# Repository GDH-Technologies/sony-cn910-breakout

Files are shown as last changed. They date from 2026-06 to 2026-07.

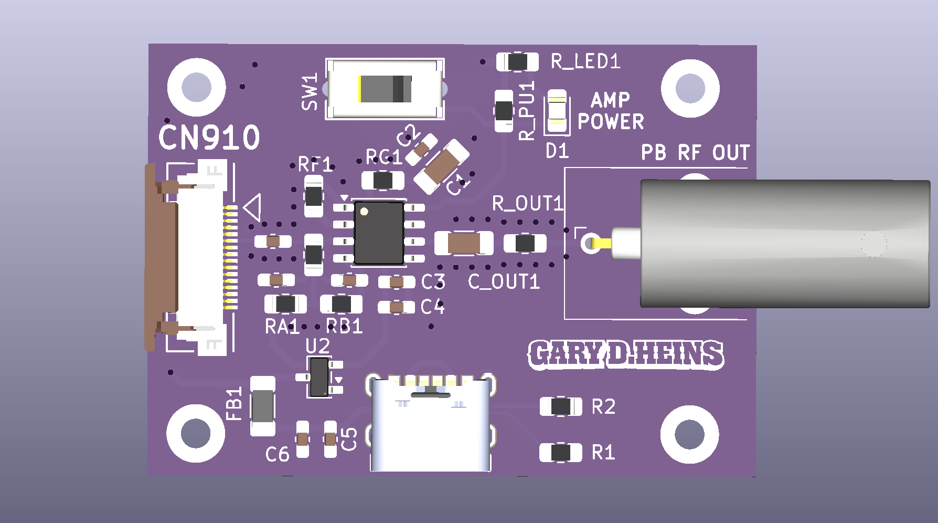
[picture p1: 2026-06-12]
kicad-cn910/CN910 Breakout with Amp/CN910 Breakout with Amp.png

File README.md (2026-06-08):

# sony-cn910-breakout

Repository for schematics and PCBs for using Sony Camcorders with the VC-195 board and CN910 FPC service port.

The full version is for connecting to the service ports (CN910) of my sony handycams and 1. amplifying the FM RF signal for `vhs-decode` and 2. using a raspberry pi to interface with the camcorder via LANC.

The simplified version is simply meant to give me the ability to connect to the camcorder's FM RF output for external amplification. Only the `PB RF`, `REC RF`, and `REG GND` pins of CN910 are available for connection via SMA jack. A few other CN910 signals have test points, but the FM RF signals are the only ones with an SMA connection.

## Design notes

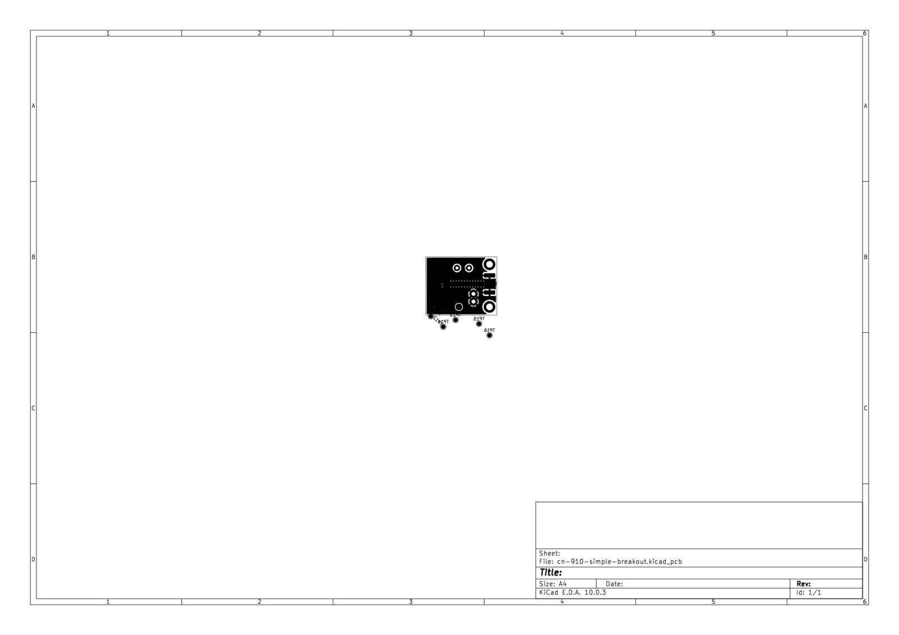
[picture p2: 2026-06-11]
kicad-cn910/CN910 Breakout/cn-910-simple-breakout_2d_view.png

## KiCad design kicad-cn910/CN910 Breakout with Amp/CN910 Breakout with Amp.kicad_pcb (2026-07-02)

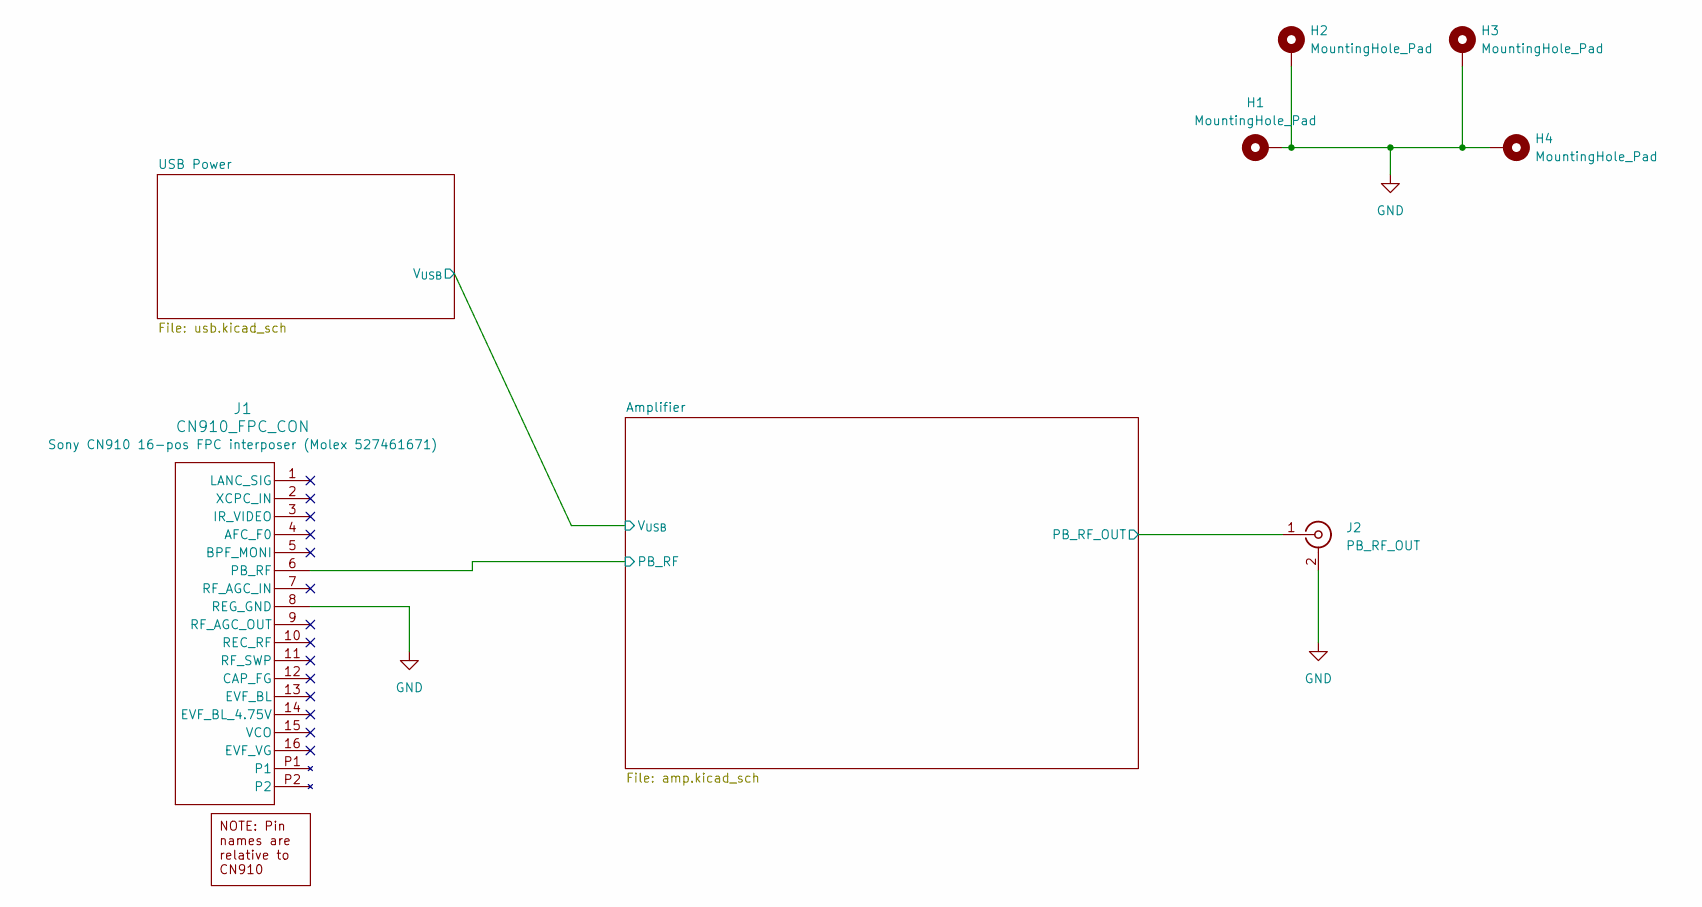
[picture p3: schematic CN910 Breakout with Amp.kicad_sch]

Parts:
H1, H2, H3, H4: MountingHole_Pad; MountingHole_2.2mm_M2_Pad_TopBottom
J1: CN910_FPC_CON; CON_527461671_MOL; MPN 527461671
J2: PB_RF_OUT; Molex_0731000154_BNC_RA_THT

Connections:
/Amplifier/PB_RF: J1.6 (PB_RF); also elsewhere on the board
/Amplifier/PB_RF_OUT: J2.1 (In); also elsewhere on the board
GND: H1.1 (1_1), H2.1 (1_1), H3.1 (1_1), H4.1 (1_1), J1.8 (REG_GND), J2.2 (Ext); also elsewhere on the board

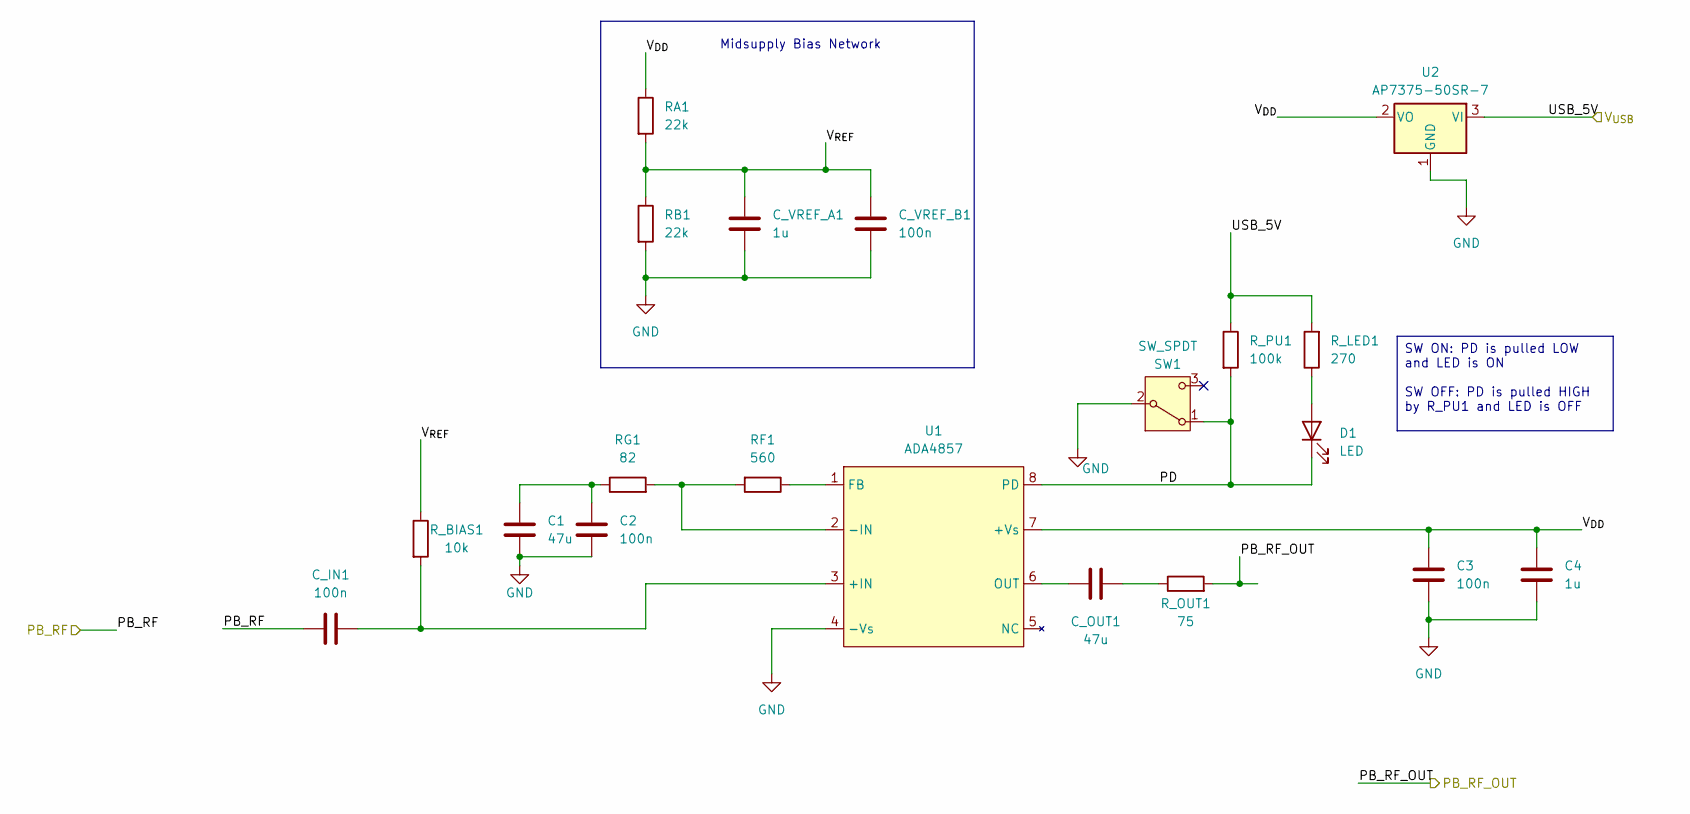
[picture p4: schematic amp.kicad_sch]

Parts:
C1: 47u; C_1206_3216Metric_Pad1.33x1.80mm_HandSolder
C2, C3: 100n; C_0603_1608Metric_Pad1.08x0.95mm_HandSolder
C4: 1u; C_0603_1608Metric_Pad1.08x0.95mm_HandSolder
C_IN1: 100n; C_0603_1608Metric_Pad1.08x0.95mm_HandSolder
C_OUT1: 47u; C_1206_3216Metric_Pad1.33x1.80mm_HandSolder; MFR.Part CL31A476MPHNNNE; LCSC C96123
C_VREF_A1: 1u; C_0603_1608Metric_Pad1.08x0.95mm_HandSolder
C_VREF_B1: 100n; C_0603_1608Metric_Pad1.08x0.95mm_HandSolder
D1: LED; LED_0805_2012Metric_Pad1.15x1.40mm_HandSolder
RA1: 22k; R_0805_2012Metric_Pad1.20x1.40mm_HandSolder
RB1: 22k; R_0805_2012Metric_Pad1.20x1.40mm_HandSolder
RF1: 560; R_0805_2012Metric_Pad1.20x1.40mm_HandSolder
RG1: 82; R_0805_2012Metric_Pad1.20x1.40mm_HandSolder
R_BIAS1: 10k; R_0805_2012Metric_Pad1.20x1.40mm_HandSolder
R_LED1: 270; R_0805_2012Metric_Pad1.20x1.40mm_HandSolder
R_OUT1: 75; R_0805_2012Metric_Pad1.20x1.40mm_HandSolder; MFR.Part 0603WAF750JT5E; LCSC C4275
R_PU1: 100k; R_0805_2012Metric_Pad1.20x1.40mm_HandSolder
SW1: SW_SPDT; Slide_Switch_SS12D07_CNK
U1: ADA4857; ADA4857-1YRZ-R7; MFR.Part ADA4857-1YRZ-R7; LCSC C208021
U2: AP7375-50SR-7; SOT-23-3

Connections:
/Amplifier/PB_RF: C_IN1.1; also elsewhere on the board
/Amplifier/PB_RF_OUT: R_OUT1.2; also elsewhere on the board
/Amplifier/PD: D1.1 (K), R_PU1.2, SW1.1 (A), U1.8 (PD)
/Amplifier/USB_5V: R_LED1.2, R_PU1.1, U2.3 (VI); also elsewhere on the board
/Amplifier/V_{DD}: C3.1, C4.1, RA1.1, U1.7 (+Vs), U2.2 (VO)
/Amplifier/V_{REF}: C_VREF_A1.1, C_VREF_B1.2, RA1.2, RB1.1, R_BIAS1.1
GND: C1.2, C2.2, C3.2, C4.2, C_VREF_A1.2, C_VREF_B1.1, RB1.2, SW1.2 (B), U1.4 (-Vs), U2.1 (GND); also elsewhere on the board
unnamed: C1.1, C2.1, RG1.1
unnamed: C_OUT1.1, R_OUT1.1
unnamed: D1.2 (A), R_LED1.1
unnamed: C_IN1.2, R_BIAS1.2, U1.3 (+IN)
unnamed: RF1.2, RG1.2, U1.2 (-IN)
unnamed: RF1.1, U1.1 (FB)
unnamed: C_OUT1.2, U1.6 (OUT)

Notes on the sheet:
Midsupply Bias Network
SW ON: PD is pulled LOW and LED is ON SW OFF: PD is pulled HIGH by R_PU1 and LED is OFF

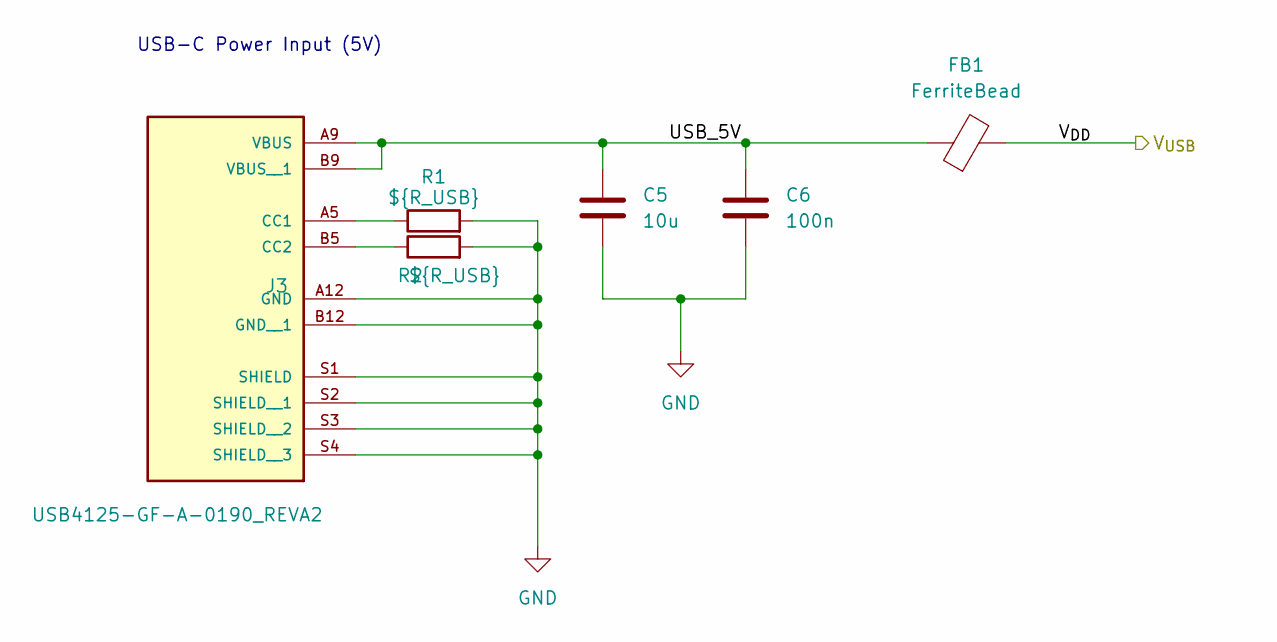
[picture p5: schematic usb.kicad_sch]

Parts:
C5: 10u; C_0603_1608Metric_Pad1.08x0.95mm_HandSolder
C6: 100n; C_0603_1608Metric_Pad1.08x0.95mm_HandSolder
FB1: FerriteBead; L_1206_3216Metric_Pad1.22x1.90mm_HandSolder
J3: USB4125-GF-A-0190_REVA2; GCT_USB4125-GF-A-0190_REVA2; PARTREV Rev A2
R1, R2: ${R_USB}; R_0805_2012Metric_Pad1.20x1.40mm_HandSolder

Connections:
/Amplifier/USB_5V: FB1.2; also elsewhere on the board
/USB Power/USB_5V: C5.1, C6.1, FB1.1, J3.A9 (VBUS), J3.B9 (VBUS__1)
GND: C5.2, C6.2, J3.A12 (GND), J3.B12 (GND__1), J3.S1 (SHIELD), J3.S2 (SHIELD__1), J3.S3 (SHIELD__2), J3.S4 (SHIELD__3), R1.2, R2.2; also elsewhere on the board
unnamed: J3.A5 (CC1), R1.1
unnamed: J3.B5 (CC2), R2.1

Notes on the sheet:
USB-C Power Input (5V)

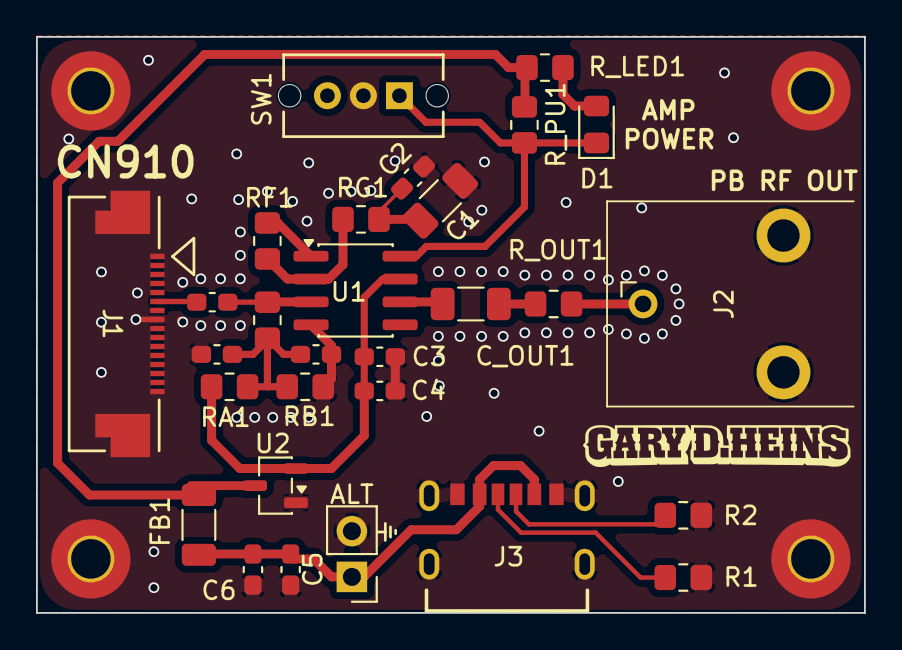
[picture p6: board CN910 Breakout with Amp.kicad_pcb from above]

Board: 2 copper layers, 46.0 x 32.0 mm, 33 parts (0 on the bottom side), 17 nets.

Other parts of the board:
SONY_AMP**: Board

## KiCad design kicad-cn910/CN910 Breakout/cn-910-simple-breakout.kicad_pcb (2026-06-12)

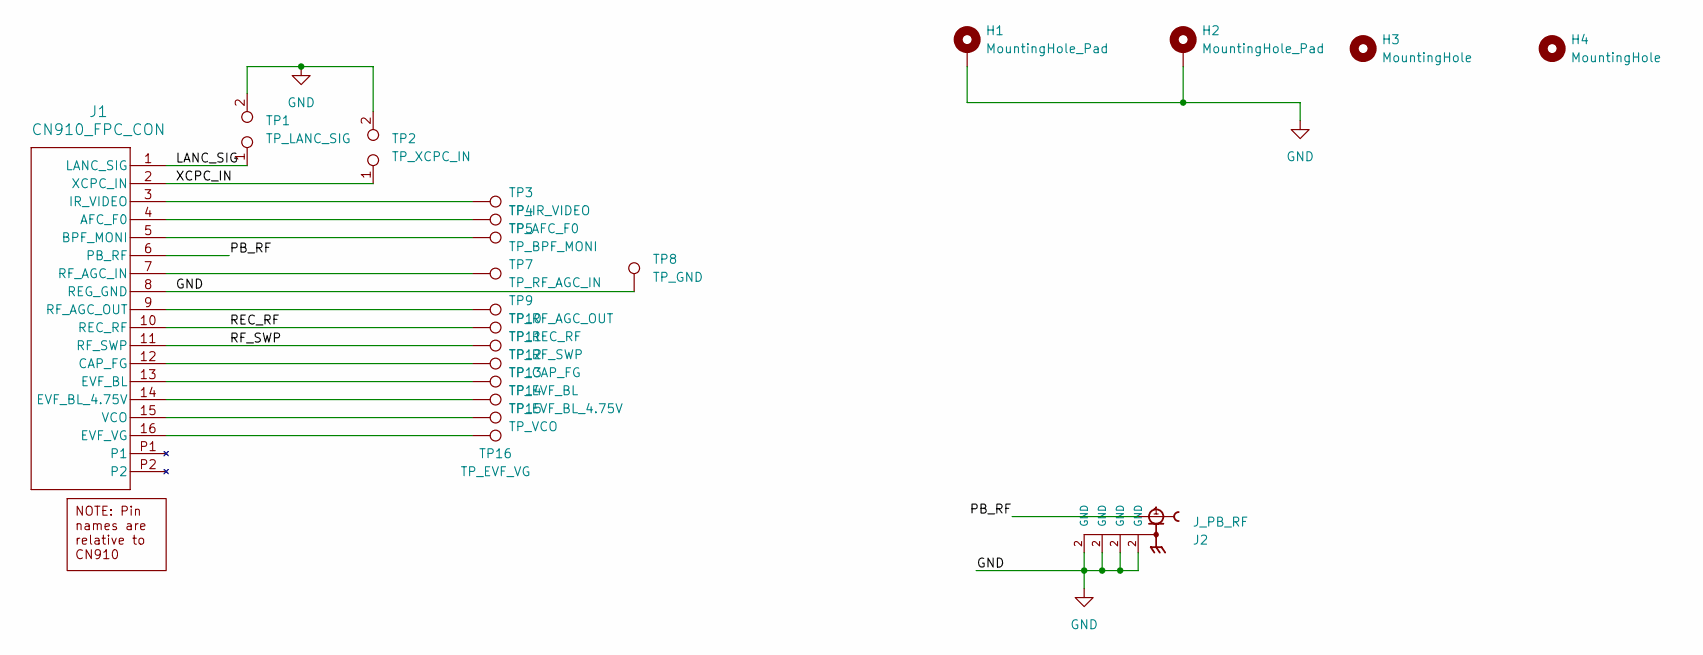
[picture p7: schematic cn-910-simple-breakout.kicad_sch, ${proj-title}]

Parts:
H1, H2: MountingHole_Pad; MountingHole_2.2mm_M2_ISO14580_Pad
H3, H4: MountingHole; MountingHole_2.2mm_M2_ISO14580
J1: CN910_FPC_CON; CON_527461671_MOL; MPN 527461671
J2: J_PB_RF; SMA_Samtec_SMA-J-P-H-ST-EM1_EdgeMount; PARTREV 1.0
TP1: TP_LANC_SIG; PinHeader_1x02_P2.54mm_Vertical
TP2: TP_XCPC_IN; PinHeader_1x02_P2.54mm_Vertical
TP3: TP_IR_VIDEO; TestPoint_Pad_D1.5mm
TP4: TP_AFC_F0; TestPoint_Pad_D1.5mm
TP5: TP_BPF_MONI; TestPoint_Pad_D1.5mm
TP7: TP_RF_AGC_IN; TestPoint_Pad_D1.5mm
TP8: TP_GND; TestPoint_Bridge_Pitch2.54mm_Drill1.3mm
TP9: TP_RF_AGC_OUT; TestPoint_Pad_D1.5mm
TP10: TP_REC_RF; TestPoint_Pad_D1.5mm
TP11: TP_RF_SWP; TestPoint_Pad_D1.5mm
TP12: TP_CAP_FG; TestPoint_Pad_D1.5mm
TP13: TP_EVF_BL; TestPoint_Pad_D1.5mm
TP14: TP_EVF_BL_4.75V; TestPoint_Pad_D1.5mm
TP15: TP_VCO; TestPoint_Pad_D1.5mm
TP16: TP_EVF_VG; TestPoint_Pad_D1.5mm

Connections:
/LANC_SIG: J1.1 (LANC_SIG), TP1.1
/PB_RF: J1.6 (PB_RF), J2.1
/REC_RF: J1.10 (REC_RF), TP10.1 (1_1)
/RF_SWP: J1.11 (RF_SWP), TP11.1 (1_1)
/XCPC_IN: J1.2 (XCPC_IN), TP2.1
GND: H1.1 (1_1), H2.1 (1_1), J1.8 (REG_GND), J2.2 (GND_2), TP1.2, TP2.2, TP8.1 (1_1)
unnamed: J1.4 (AFC_F0), TP4.1 (1_1)
unnamed: J1.5 (BPF_MONI), TP5.1 (1_1)
unnamed: J1.12 (CAP_FG), TP12.1 (1_1)
unnamed: J1.13 (EVF_BL), TP13.1 (1_1)
unnamed: J1.14 (EVF_BL_4.75V), TP14.1 (1_1)
unnamed: J1.16 (EVF_VG), TP16.1 (1_1)
unnamed: J1.3 (IR_VIDEO), TP3.1 (1_1)
unnamed: J1.7 (RF_AGC_IN), TP7.1 (1_1)
unnamed: J1.9 (RF_AGC_OUT), TP9.1 (1_1)
unnamed: J1.15 (VCO), TP15.1 (1_1)

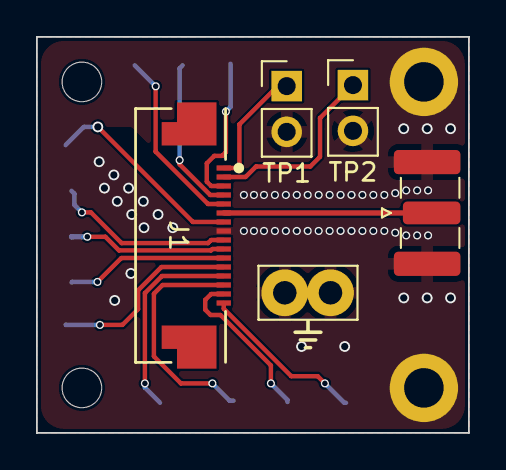
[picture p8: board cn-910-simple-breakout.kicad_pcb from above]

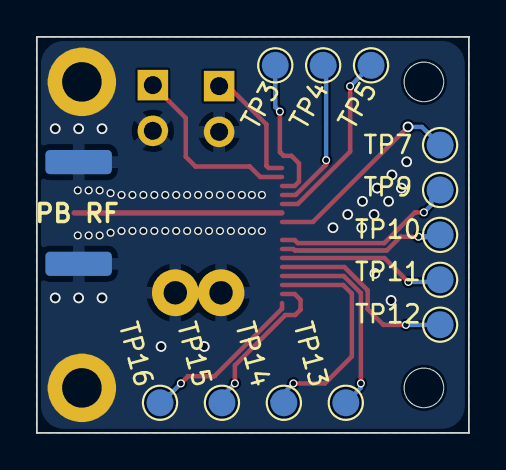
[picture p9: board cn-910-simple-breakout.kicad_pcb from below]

Board: 2 copper layers, 24.0 x 22.0 mm, 22 parts (12 on the bottom side), 16 nets.

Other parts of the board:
SONY_SIMPLE**: Board

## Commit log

2026-04-22 Adding KiCad project
    [cn910-breakout.kicad_sch, lanc.kicad_sch, pb-rf-amp-lpf.kicad_sch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]
2026-04-23 PCB work
    [cn910-breakout.kicad_sch, pi_pico.kicad_sch]
2026-04-23 Wired up scope checking SMA connectors
    [lanc.kicad_sch, pi_pico.kicad_sch]
2026-04-24 Nearly finalized Sony CN910 PCB and added archives of the modified clockgen main board and CX card jig
    [cn910-breakout.kicad_sch, pi_pico.kicad_sch]
2026-04-28 Refined routing
    [cn910-breakout.kicad_pcb, cn910-breakout.kicad_sch, lanc.kicad_sch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]
2026-06-05 Updated KiCad project files for CN910 breakout, including version upgrades to 10.0, added new components, and refined design settings. Added .gitignore entries for KiCad artifacts and included a new 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
    [cn-910-simple-breakout.kicad_pcb, cn-910-simple-breakout.kicad_sch, cn910-breakout.kicad_pcb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]
2026-06-05 Enhanced CN910 breakout KiCad project with updated design rules, added new components, and refined PCB layout. Introduced a new simple breakout PCB with detailed Gerber files for manufacturing. Updat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
    [cn-910-simple-breakout-B_Cu.gbr, cn-910-simple-breakout-B_Mask.gbr, cn-910-simple-breakout-B_Paste.gbr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]
2026-06-05 Updated interactive BOM for the CN910 breakout project, changing the title to "Sony CCD-TRV615 Amp BOM" and refining the configuration settings. Removed unused fields from the BOM configuration for i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
2026-06-06 Refactored CN910 breakout KiCad project files, updating footprint and symbol references to "GDH" naming convention. Adjusted PCB thickness and dielectric properties for improved design accuracy. Adde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
    [cn-910-simple-breakout.kicad_pcb, cn-910-simple-breakout.kicad_sch, cn910-breakout.kicad_pcb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]
2026-06-06 Updated CN910 breakout KiCad project files with dynamic project metadata, including title, company, version, and license. Refined design rules and component properties for improved clarity and organi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
    [cn-910-simple-breakout.kicad_pcb, cn-910-simple-breakout.kicad_sch, cn910-breakout.kicad_pcb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]
2026-06-06 Updated CN910 breakout KiCad project files to reflect JLCPCB manufacturing specifications, including revised design rules for track width, via dimensions, and hole clearances. Adjusted component prop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
    [cn-910-simple-breakout.kicad_pcb, cn-910-simple-breakout.kicad_sch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]
2026-06-08 Add Gerber files and library tables for cn-910-simple-breakout project
    - Created new Gerber file for PTH drill: cn-910-simple-breakout-PTH-drl.gbr
    - Added job file for Gerber generation: cn-910-simple-breakout-job.gbrjob
    - Initialized footprint library table: fp-lib-table
    - Initialized symbol library table: sym-lib-table
    [cn-910-simple-breakout-B_Cu.gbr, cn-910-simple-breakout-B_Mask.gbr, cn-910-simple-breakout-B_Paste.gbr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]
2026-06-08 Update CN910 breakout PCB properties and add user text for Molex part number
    [cn-910-simple-breakout.kicad_pcb]
2026-06-11 Refactor code structure for improved readability and maintainability
    [CN910 Breakout with Amp.kicad_pcb, CN910 Breakout with Amp.kicad_sch, amp.kicad_sch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]
2026-07-02 Fixed CN910 pin 7/8 routing in the breakout with amp design. RF_AGC_IN (pin 7) was mistakenly tied to GND instead of REG_GND (pin 8).
    [CN910 Breakout with Amp.kicad_pcb, CN910 Breakout with Amp.kicad_sch]
